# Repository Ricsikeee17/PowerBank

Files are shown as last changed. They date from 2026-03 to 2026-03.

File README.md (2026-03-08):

# Custom PowerBank

This is a custom made powerbank from scratch that will use 18650 batteries from a laptop battery. I made this because I had some laying 18650 batteries and I need a powerbank for my phone because I doesn't hold the charge through the day. It will have one USB C port to charge itself and your phone.

## PCB

I made the PCB with KiCAD and here's some screenshot of the schematic and the PCB:



## CAD Model

The CAD model was made in Shapr3D it's fully 3D printable. It's only 2 parts and I think I will glue the together when assembling it.

A screenshot:
{5D32E746-1B3C-468F-AC42-E1E89CABE559}

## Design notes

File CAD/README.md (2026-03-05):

{5D32E746-1B3C-468F-AC42-E1E89CABE559}

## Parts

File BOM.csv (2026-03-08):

Item | Qty. | Price(RON) | Price(USD) | Link
598-2200-107F | 5 | 6.80 RON | 1.55$ | https://ro.farnell.com/dialight/598-2200-107f/led-white-1cd-1206/dp/4227196
0805ZD226MAT2A | 5 | 8.80 RON | 2.01$ | https://ro.farnell.com/avx/0805zd226mat2a/cap-22-f-10v-20-x5r-0805/dp/1867956
885012107014 | 5 | 10.70 RON | 2.44$ | https://ro.farnell.com/wurth-elektronik/885012107014/cap-10-f-16v-20-x5r-0805/dp/2495153
VLS4012HBX-R68M-N | 1 | 2.29 RON | 0.52$ | https://ro.farnell.com/tdk/vls4012hbx-r68m-n/power-inductor-680nh-shielded/dp/4125677
CC0805MRY5V9BB104 | 10 | 2.00 RON | 0.46$ | https://ro.farnell.com/yageo/cc0805mry5v9bb104/capacitor-0-1uf-y5v-0805/dp/4255666
12401610E4 2A | 5 | 34.49 RON | 7.87$ | https://www.aliexpress.com/item/1005006352991426.html?spm=a2g0o.cart.0.0.6da538daUigyTi&mp=1
IP5306 | 5 | 6.05 RON | 1.38$ | https://www.aliexpress.com/item/4000117960810.html?spm=a2g0o.cart.0.0.6da538daUigyTi&mp=1
Aliexpress shipping | - | 69.98 RON | 15.74 | -
PCB+shipping | 5 | 6.57 RON | 1.50$ | https://jlcpcb.com/
Farnell shipping | - | 34.99 RON | 7.98 | -

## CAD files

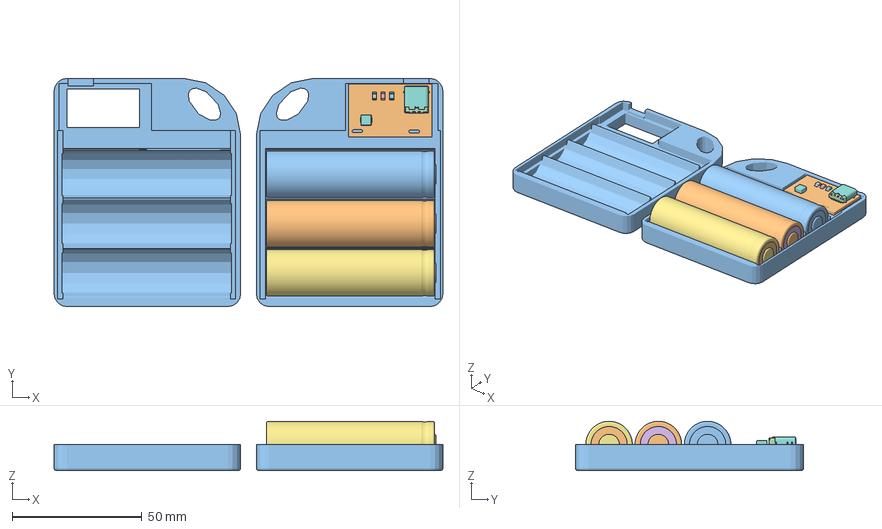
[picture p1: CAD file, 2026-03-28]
CAD/PowerBankCAD.3mf
150.0 x 88.0 x 19.0 mm
Mesh_body_258
Imported_05
Mesh_body_221
Mesh_body_622
Mesh_body_140
Mesh_body_71
Mesh_body_183
Mesh_body_709
Mesh_body_305
Mesh_body_60
Mesh_body_366
Imported_42
Mesh_body_470
Mesh_body_137
Mesh_body_441
Mesh_body_563
Mesh_body_675
Mesh_body_210
Mesh_body_844
Mesh_body_157
Mesh_body_521
Mesh_body_798
Mesh_body_786
Mesh_body_365
Imported_01
Mesh_body_372
Mesh_body_23
Mesh_body_157_(2)
Mesh_body_26
Mesh_body_506
Mesh_body_267
Mesh_body_47
Mesh_body_386
Mesh_body_54
Mesh_body_288
Imported_11
Mesh_body_888
Mesh_body_329
Mesh_body_25
Imported_02
Mesh_body_230
Mesh_body_882
Imported_45
Mesh_body_488
Mesh_body_848
Imported_25
Mesh_body_943
Imported_03
Mesh_body_544
Mesh_body_442
Mesh_body_926
Imported_43
Mesh_body_79
Mesh_body_584
Imported_04
Mesh_body_48
Mesh_body_731
Mesh_body_55
Imported_35
Mesh_body_937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

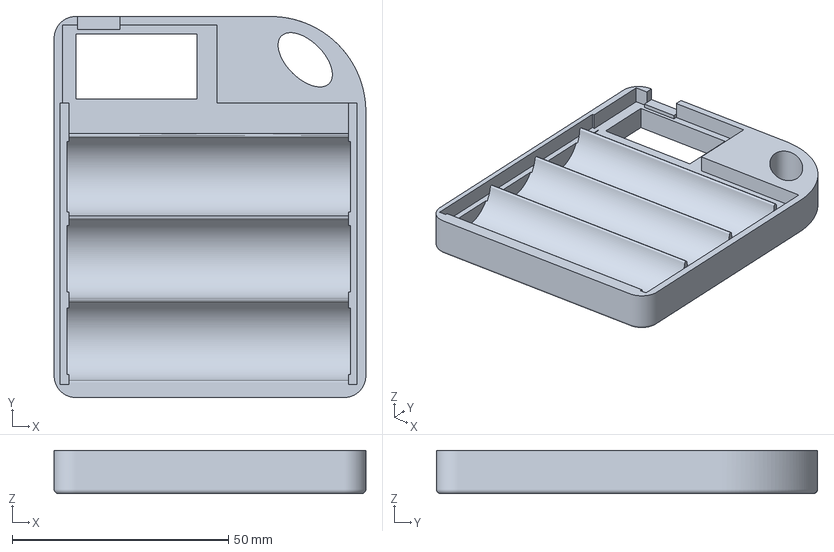
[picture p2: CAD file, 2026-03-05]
Production/PowerBank_BOTTOM.3mf
72.0 x 88.0 x 10.0 mm

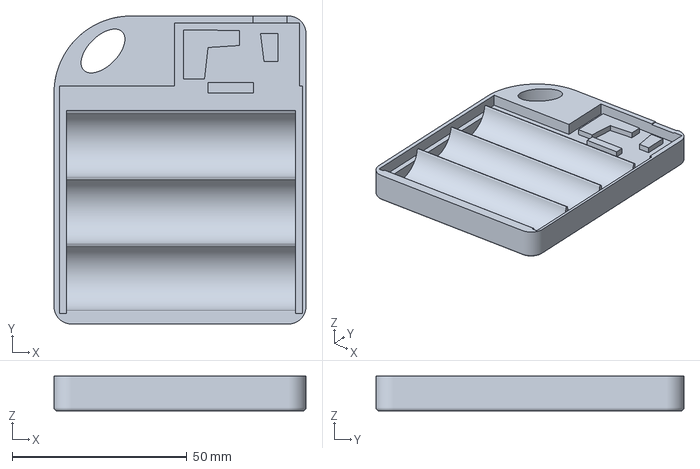
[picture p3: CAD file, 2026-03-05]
Production/PowerBank_TOP.3mf
72.0 x 88.0 x 10.0 mm

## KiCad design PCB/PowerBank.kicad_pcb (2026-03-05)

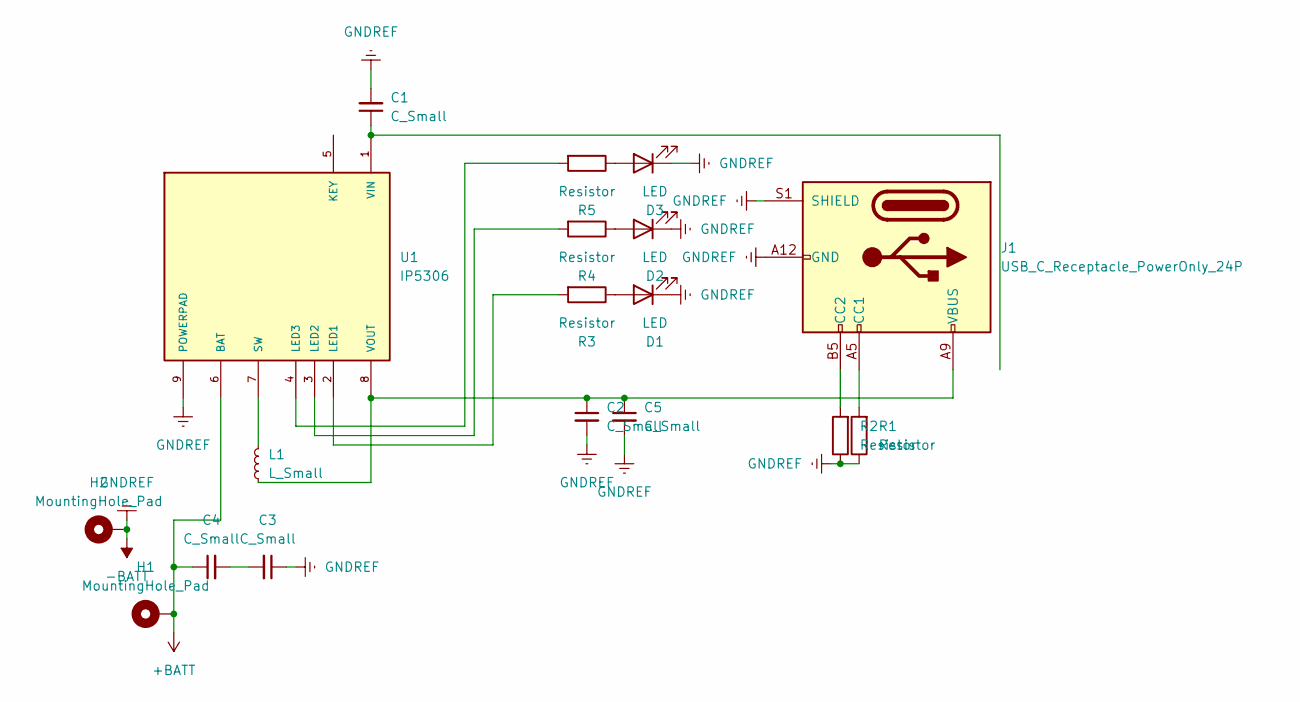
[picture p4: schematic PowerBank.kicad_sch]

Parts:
C1, C2, C3, C4, C5: C_Small; C_0805_2012Metric
D1, D2, D3: LED; LED_1206_3216Metric
H1: MountingHole_Pad; BATT+_MOUNTING_HOLE
H2: MountingHole_Pad; BATT-_MOUNTING_HOLE
J1: USB_C_Receptacle_PowerOnly_24P; USB_C_Receptacle_Amphenol_12401610E4-2A_CircularHoles
L1: L_Small; L_Vishay_IHLP-1616
R1, R2, R3, R4, R5: Resistor; R_0805_2012Metric
U1: IP5306; SOP127P600X165-9N; PARTREV 1.31

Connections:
+BATT: C4.1, H1.1, U1.6 (BAT)
-BATT: C1.2, C2.2, C3.1, C5.2, D1.1 (K), D2.1 (K), D3.1 (K), H2.1, J1.A1 (GND), J1.A12 (GND), J1.B1 (GND), J1.B12 (GND), J1.S1 (SHIELD), R1.1, R2.1, U1.9 (POWERPAD)
unnamed: C3.2, C4.2
unnamed: D1.2 (A), R3.1
unnamed: D2.2 (A), R4.1
unnamed: D3.2 (A), R5.1
unnamed: J1.A5 (CC1), R1.2
unnamed: J1.B5 (CC2), R2.2
unnamed: R3.2, U1.2 (LED1)
unnamed: R4.2, U1.3 (LED2)
unnamed: R5.2, U1.4 (LED3)
unnamed: L1.2, U1.7 (SW)
unnamed: C1.1, U1.1 (VIN)
unnamed: C2.1, C5.1, J1.A4 (VBUS), J1.A9 (VBUS), J1.B4 (VBUS), J1.B9 (VBUS), L1.1, U1.8 (VOUT)

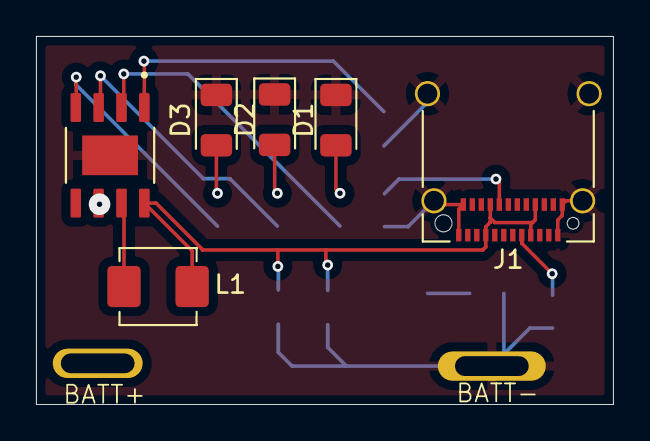
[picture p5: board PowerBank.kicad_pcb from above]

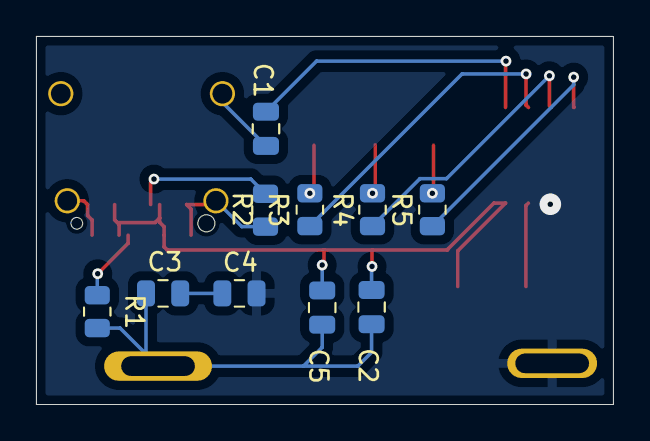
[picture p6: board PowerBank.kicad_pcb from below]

Board: 2 copper layers, 32.1 x 20.4 mm, 18 parts (10 on the bottom side), 14 nets.
